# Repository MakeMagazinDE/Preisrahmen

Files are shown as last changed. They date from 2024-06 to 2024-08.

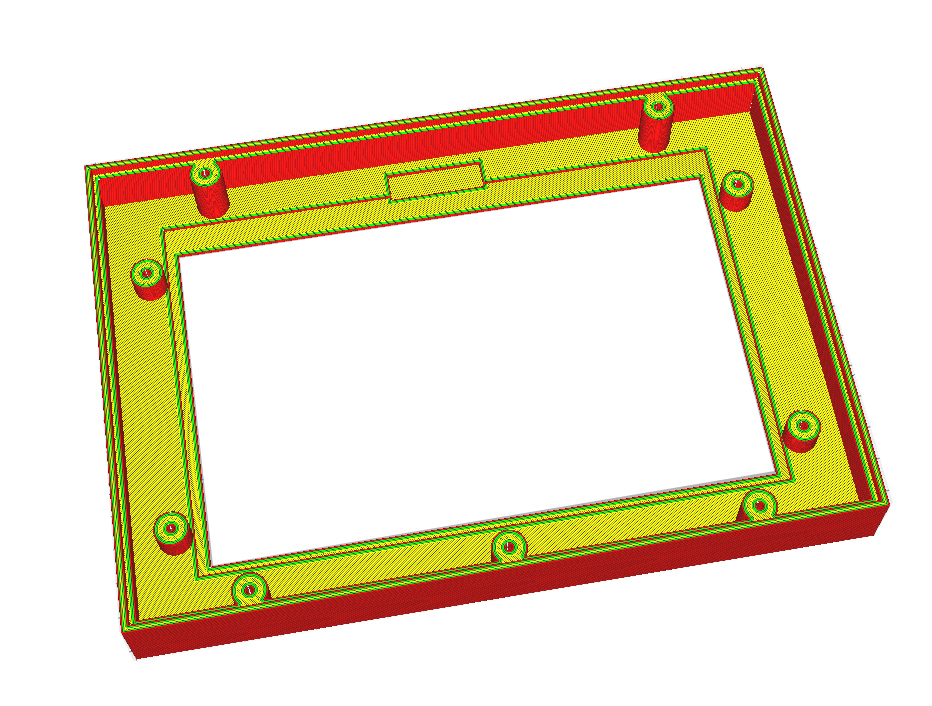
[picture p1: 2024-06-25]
3D-Druckdateien/3d-Rahmen.jpg

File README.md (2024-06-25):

GitHub Logo

Maker Media GmbH

***

# Preisrahmen

**Wer einen dynamischen Strompreisvertrag wählt, bekommt vom Energielieferanten keine festen kWh-Preise mehr, sondern stündlich wechselnde Tarife. Um die günstigsten Stunden optimal zu nutzen, haben wir unseren Preisrahmen entwickelt. Täglich ruft er die für den nächsten Tag festgelegten Preise ab und zeigt sie auf seinem ePaper-Display an.**

Preisrahmen

Der vollständige Artikel zum Projekt erscheint in der Make 4/24.

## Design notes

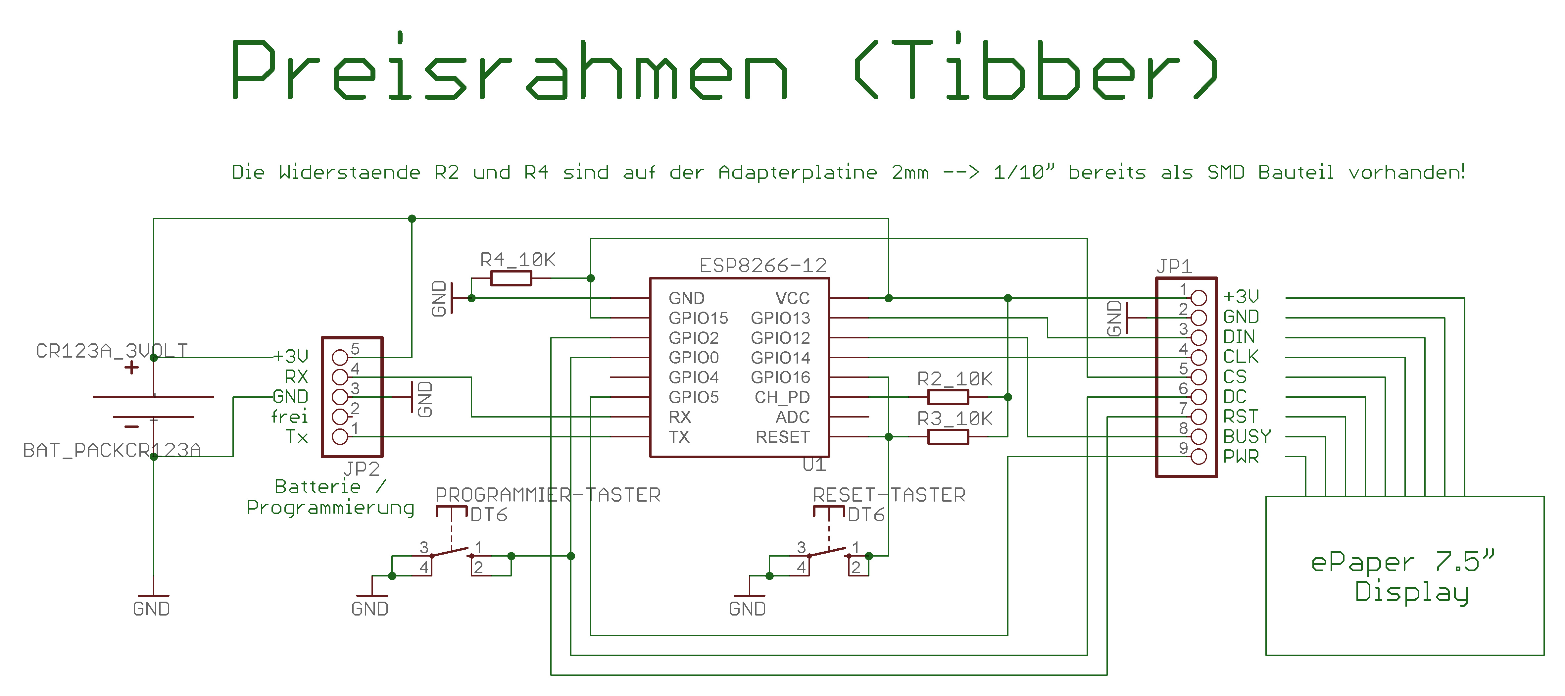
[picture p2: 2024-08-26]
Schaltplan_preisrahmen_26_08_2024.jpg

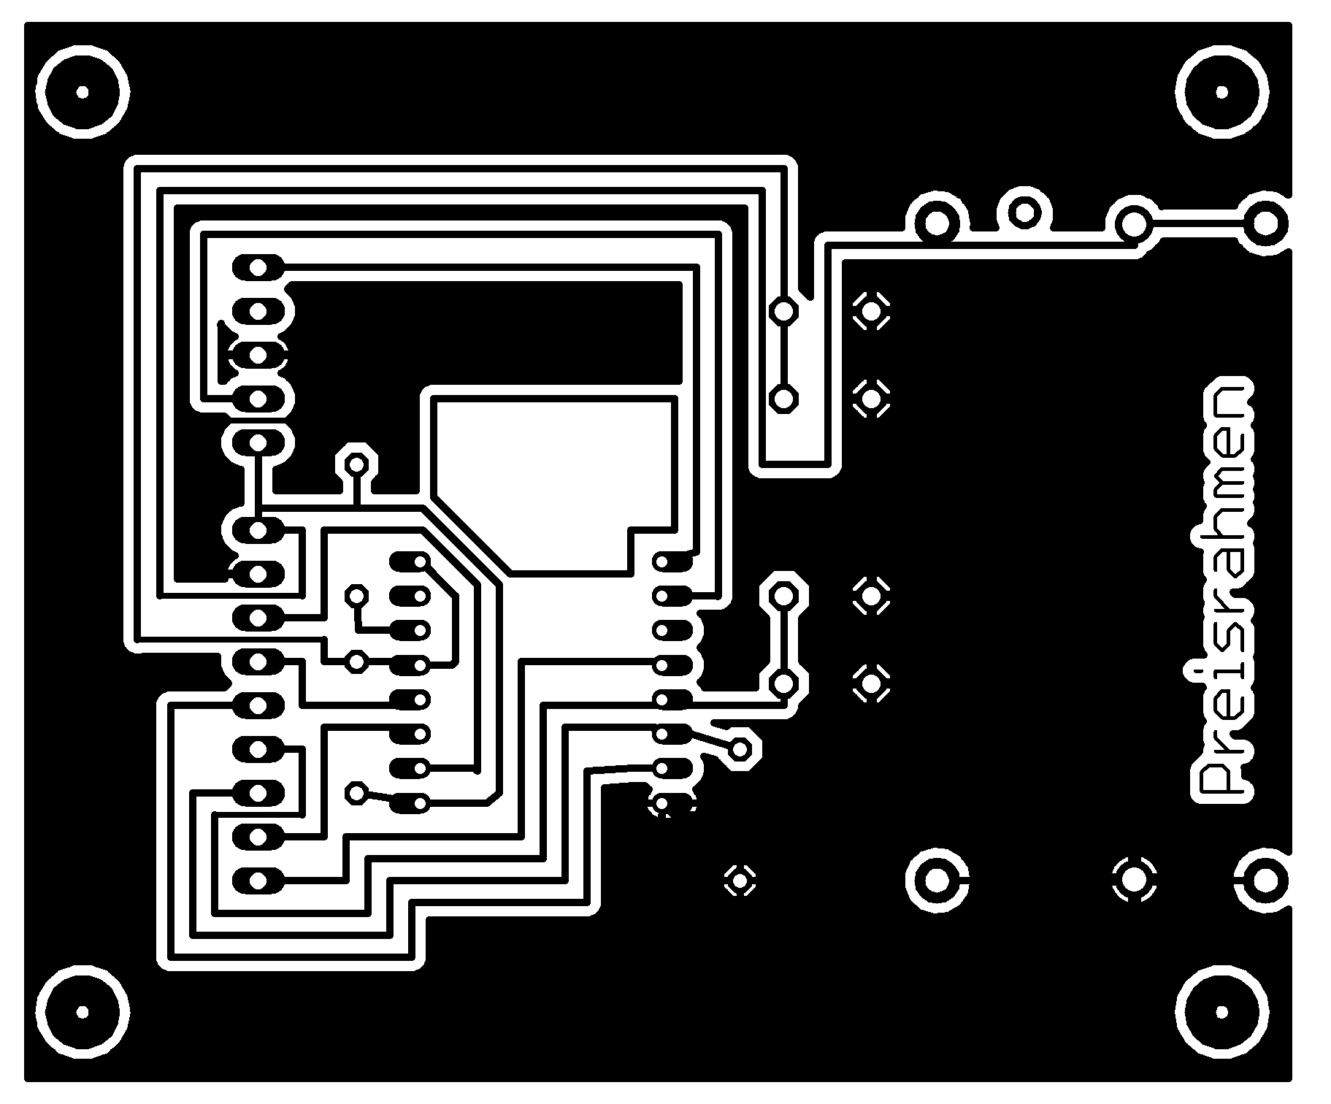
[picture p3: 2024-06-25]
Platine/Film.jpg

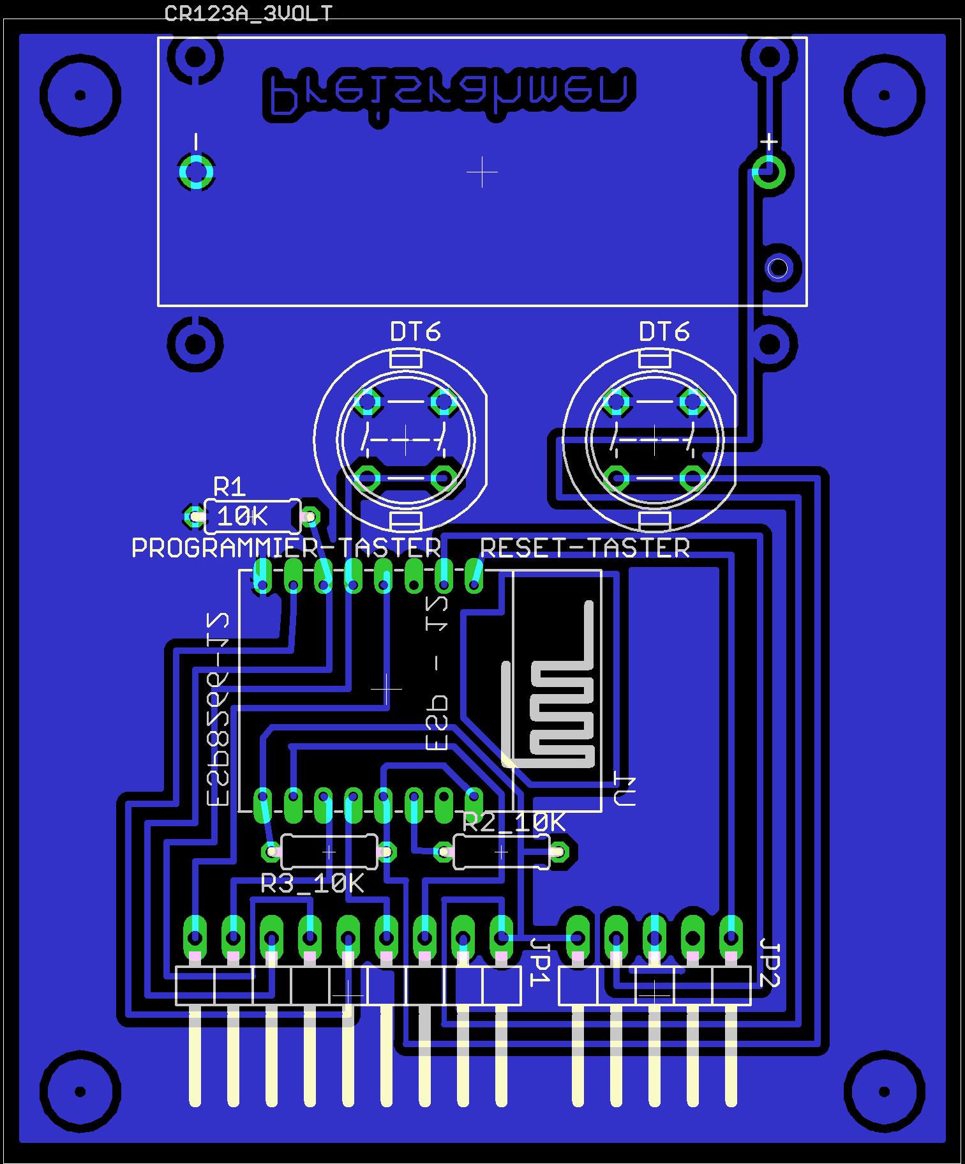
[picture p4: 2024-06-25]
Platine/Bestückungsplan.jpg

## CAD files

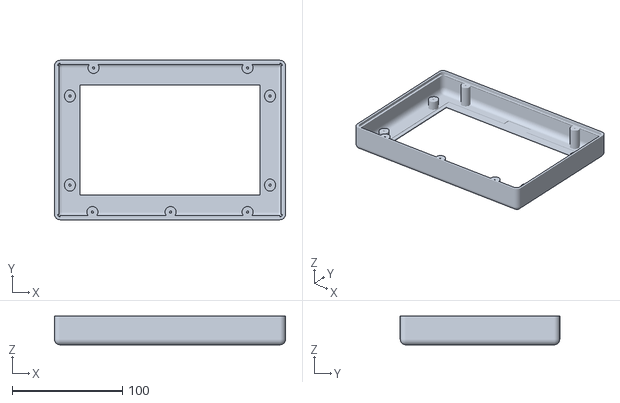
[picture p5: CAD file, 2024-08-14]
3D-Druckdateien/epaper7.5_mit_kofferecken (3).stl
210.0 x 145.0 x 26.0

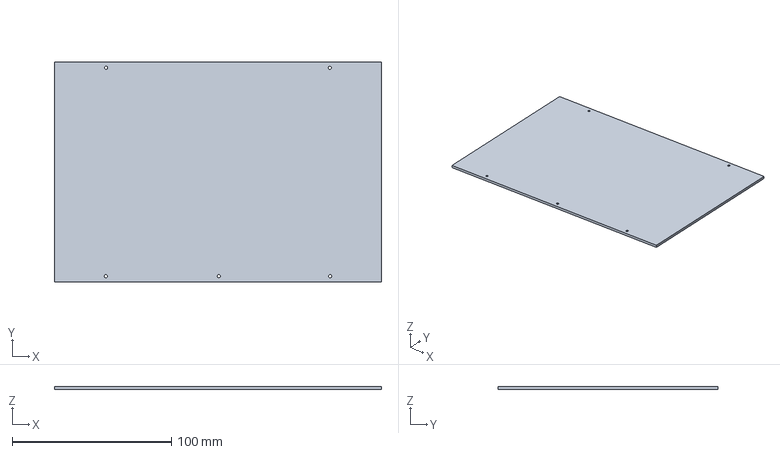
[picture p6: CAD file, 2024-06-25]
3D-Druckdateien/Cura_Rueckwand-ePaper7.5-1 (4).3mf
205.5 x 138.5 x 2.00 mm

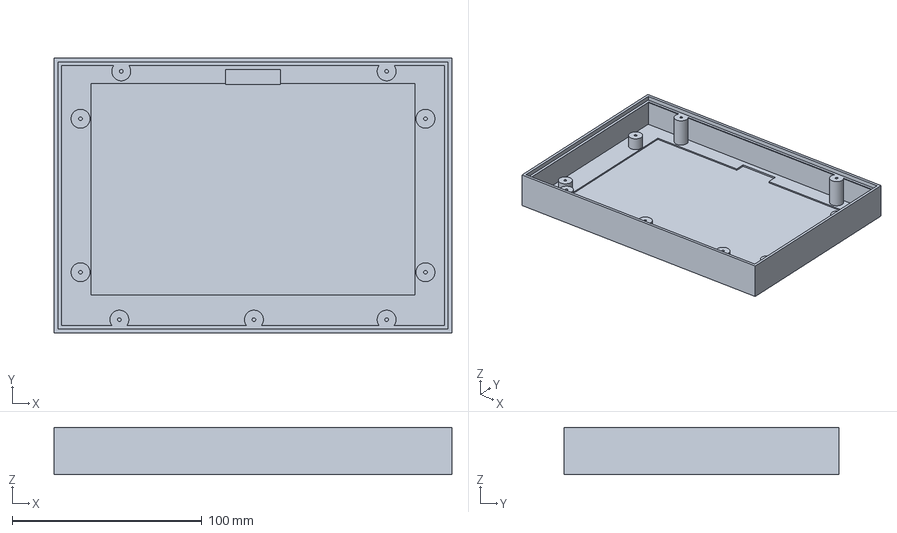
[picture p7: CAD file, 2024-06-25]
3D-Druckdateien/Cura_Rahmen-ePaper7.5-1 (1).3mf
210.0 x 145.0 x 25.0 mm

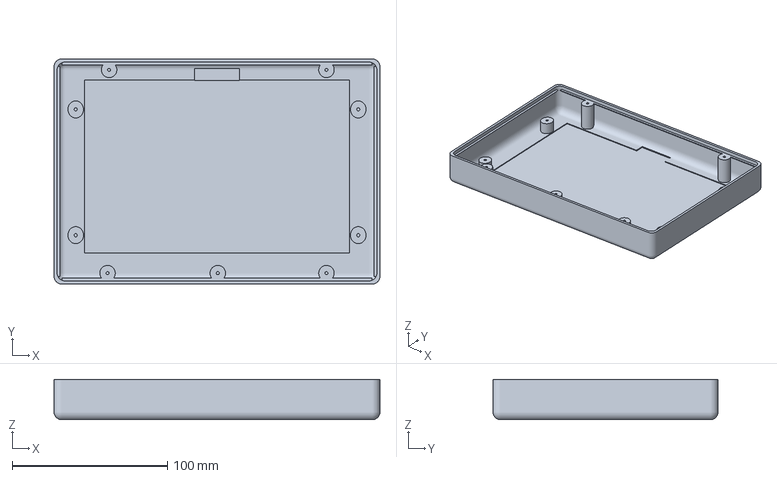
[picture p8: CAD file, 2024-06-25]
3D-Druckdateien/Rueckseite_epaper7.5kofferecken.3mf
210.0 x 145.0 x 26.0 mm

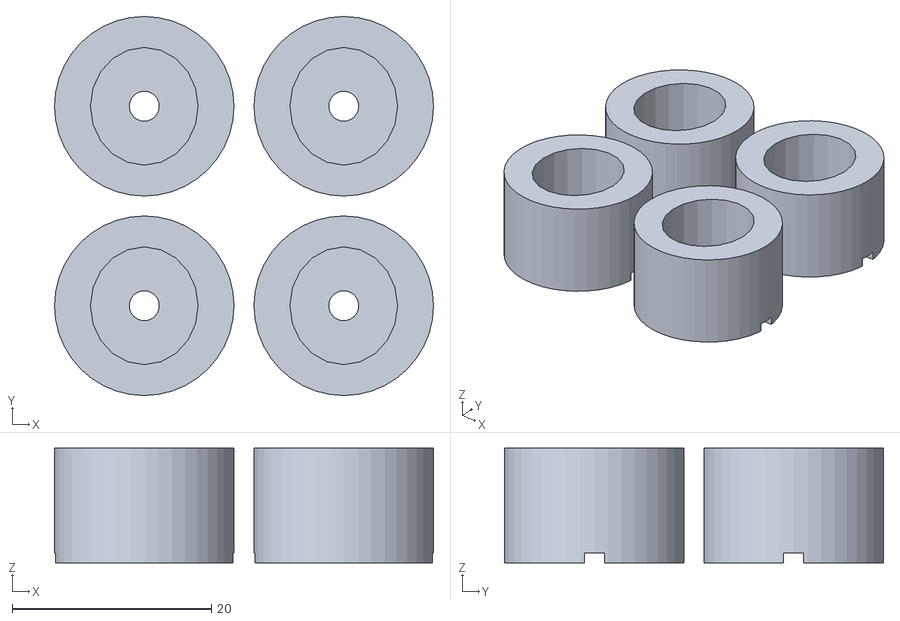
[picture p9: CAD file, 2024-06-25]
3D-Druckdateien/4xHalter_epaper7.5.stl
38.0 x 38.0 x 11.5

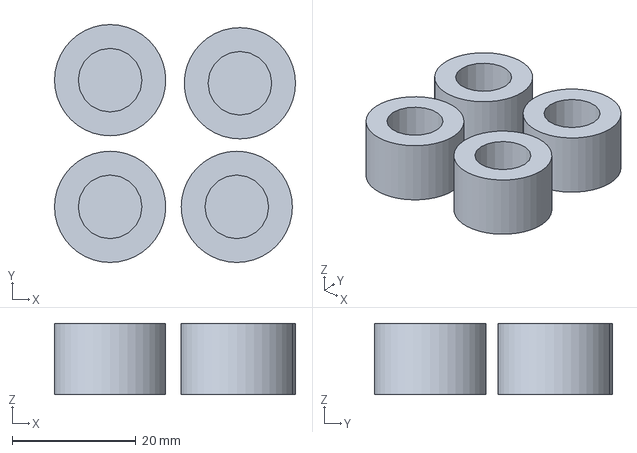
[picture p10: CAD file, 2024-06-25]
3D-Druckdateien/Befestigung_Rahmen-ePaper7.5-1 (3).3mf
39.0 x 38.5 x 11.5 mm

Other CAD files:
3D-Druckdateien/Rueckseite_epaper7.5kofferecken.stl

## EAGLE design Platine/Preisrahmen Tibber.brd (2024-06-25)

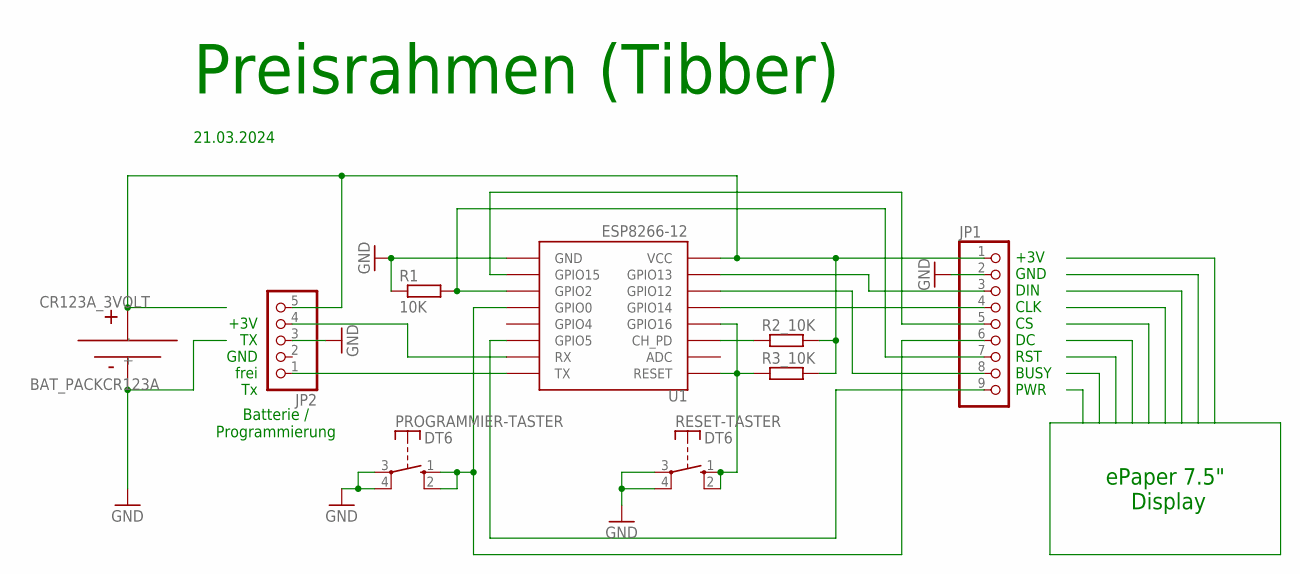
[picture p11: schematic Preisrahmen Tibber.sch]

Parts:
CR123A_3VOLT: BAT_PACKCR123A; BH123A
JP1: PINHD-1X9/90; 1X09/90
JP2: PINHD-1X5/90; 1X05/90
PROGRAMMIER-TASTER: DT6
R1: 10K; 0207/7
R2_10K, R3_10K: R-EU_0207/7; 0207/7
RESET-TASTER: DT6
U1: ESP8266-12; ESP12

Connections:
GND: CR123A_3VOLT.-, JP1.2, JP2.3, PROGRAMMIER-TASTER.3, PROGRAMMIER-TASTER.4, R1.1, RESET-TASTER.3, RESET-TASTER.4, U1.GND
unnamed: R2_10K.1, U1.CH_PD
unnamed: R3_10K.1, RESET-TASTER.1 (S), RESET-TASTER.2 (S), U1.GPIO16, U1.RESET
unnamed: JP1.7, R1.2, U1.GPIO2
unnamed: JP1.6, PROGRAMMIER-TASTER.1 (S), PROGRAMMIER-TASTER.2 (S), U1.GPIO0
unnamed: JP2.1, U1.TX
unnamed: JP2.4, U1.RX
unnamed: JP1.9, U1.GPIO5
unnamed: JP1.3, U1.GPIO13
unnamed: JP1.4, U1.GPIO14
unnamed: JP1.5, U1.GPIO15
unnamed: CR123A_3VOLT.+, JP1.1, JP2.5, R2_10K.2, R3_10K.2, U1.VCC
unnamed: JP1.8, U1.GPIO12

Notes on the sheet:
Preisrahmen (Tibber)
21.03.2024
+3V TX GND frei Tx
+3V GND DIN CLK CS DC RST BUSY PWR
ePaper 7.5" Display
Batterie / Programmierung

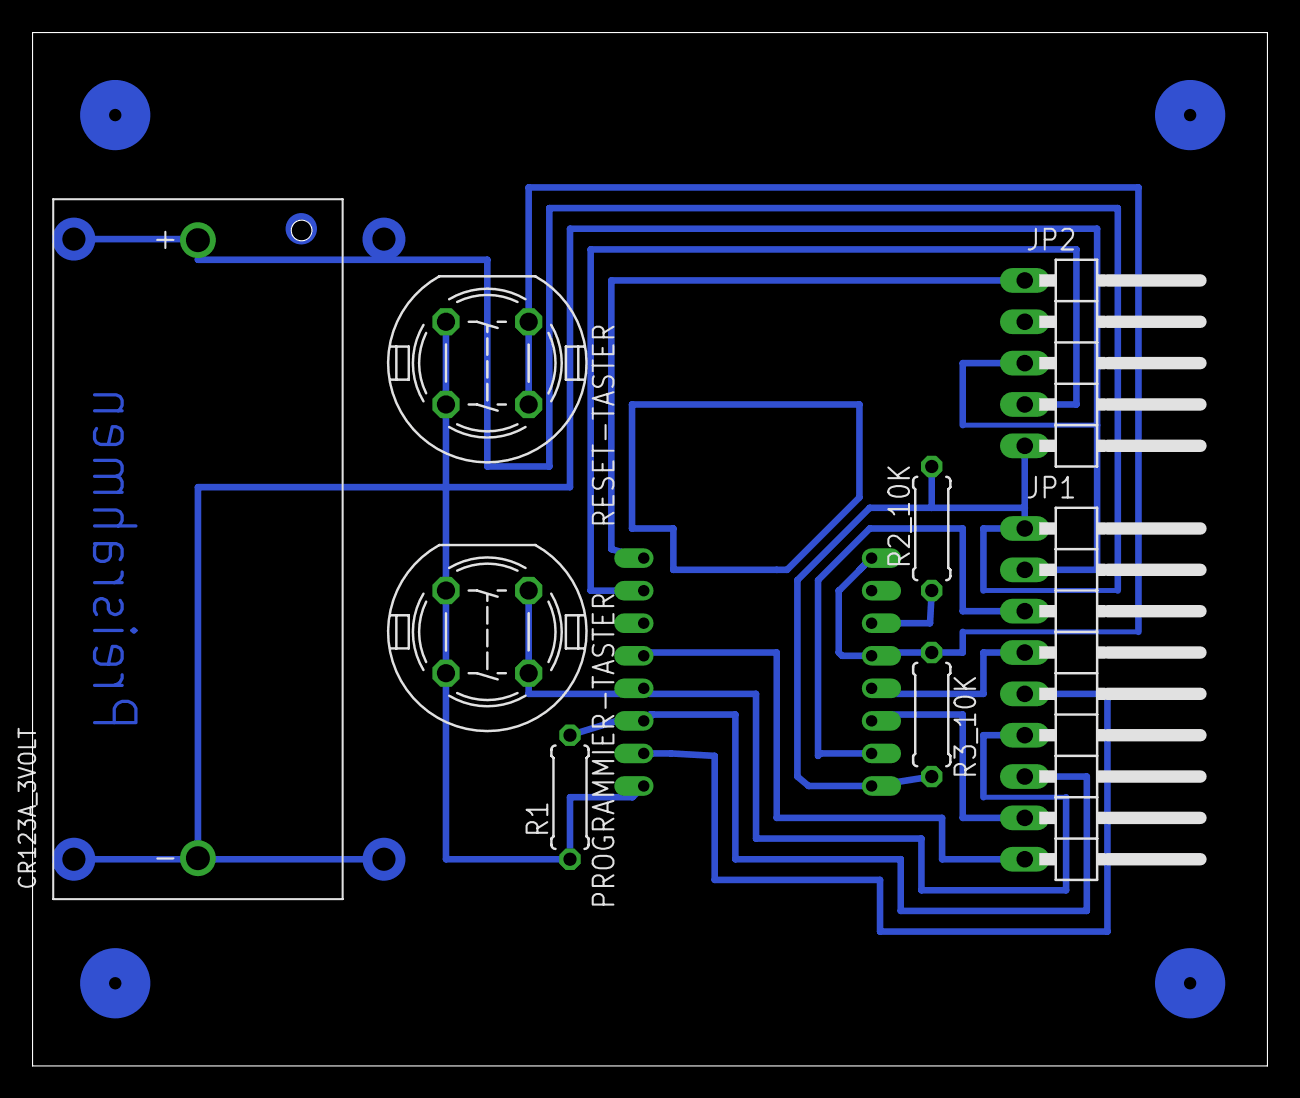
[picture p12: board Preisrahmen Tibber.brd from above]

Board: 2 copper layers, 75.9 x 63.5 mm, 9 parts (1 on the bottom side), 13 nets.

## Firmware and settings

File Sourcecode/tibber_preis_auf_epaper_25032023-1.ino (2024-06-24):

#include <dummy.h>

#define vers "Version: 11.05.2024 tibber MAKE "
const char *ssid = "Heise-Gaeste"; 
const char *password = "NurFuerHeiseGaeste!";  
const char *token = "5K4MVS-OjfWhK_4yrjOlFe1F6kJXPVf7eQYggo8ebAE"; // Demo Token durch eigenen Token ersetzen!!!
const char *tibberApi = "https://api.tibber.com/v1-beta/gql";
//############### ePaper "Gedoens" ###########################################################
#define EPD_CS SS
#define MAX_DISPLAY_BUFFER_SIZE (81920ul-34000ul-5000ul) // ~34000 base use, change 5000 to your application use
#define GxEPD2_DISPLAY_CLASS GxEPD2_BW
#define GxEPD2_DRIVER_CLASS GxEPD2_750_T7  // GDEW075T7   800x480, EK79655 (GD7965), (WFT0583CZ61)
#define MAX_HEIGHT(EPD) (EPD::HEIGHT <= (MAX_DISPLAY_BUFFER_SIZE) / (EPD::WIDTH / 2) ? EPD::HEIGHT : (MAX_DISPLAY_BUFFER_SIZE) / (EPD::WIDTH / 2))
//#if defined uwe #else #endif
#define ENABLE_GxEPD2_GFX 0  //wenn ohne Grauwerte
#include <GxEPD2_BW.h> 
#define GxEPD_LIGHTGREY GxEPD_BLACK
//Pins ePapaer an ESP8266: VCC=gr=3,3V, GND=br=GND, DIN=bl=Gpio13=D7=MOSI, CLK=ge=D5=Gpio14=SCLK, CS=or=D8=Gpio15=CS, DC=gn=D3=Gpio0, RST=ws=D4=Gpio2, BUSY=vi=D6=Gpio12=MISO, PWR=rt=3,3V
GxEPD2_DISPLAY_CLASS<GxEPD2_DRIVER_CLASS, MAX_HEIGHT(GxEPD2_DRIVER_CLASS)> display(GxEPD2_DRIVER_CLASS(/*CS=D8*/ EPD_CS, /*DC=D3*/ 0, /*RST=D4*/ 2, /*BUSY=D2*/ 4));
#include <Fonts/FreeMonoBold9pt7b.h>
//############### ePaper "Gedoens" Ende ######################################################
#include <ESP8266WiFi.h> 
#include <ESP8266HTTPClient.h> 
#include <WiFiClientSecureBearSSL.h> 
#include <ArduinoJson.h>  
#include <time.h>
#include "ota.h" 
#include "Internetzeit.h"
#define ePaper_on 5 //D1 = GPIo5
#define LED 2 //D4
#define AN LOW
#define AUS HIGH
#define RTCMEMORYSTART 65 //1.freier Speicherplatz im RTC
ADC_MODE(ADC_VCC);
char buf[200]; // Buffer für sprintf
int preis[2][24] ; //24h = 24 Preise, jeweils für den aktuellen und den folgenden Tag
int min1[2]={0,0}, max1[2]={0,0}; //jeweils für den aktuellen und den folgenden Tag
long preismittel[2]={0, 0}; //Mittelwert, jeweils für den aktuellen und den folgenden Tag
long mittelwert[2]={0,0};   //hier jetzt der Mittelwert von 13-24 Uhr des aktuellen Tages und 0-23 Uhr des folgenden Tages fuer epaper-Darstellung
int mini=30000, maxi=0, min_abgerundet, max_aufgerundet, spreizung; //fuer ePaper Darstellung
WiFiClientSecure client;  
boolean wlan_ok=false;
uint32_t bootcount, deepsleeptime; //deepsleeptime knapp unter 2hoch32, daher 22 x booten, Bootcount wird in der rtc des ESP gespeichert
unsigned long zeit_bis13; //hier wird die Zahl der Sekunden bis zum naechsten 13 Uhr gespeichert
StaticJsonDocument<1501> doc; //Speicher für die json-Daten vor dem Deserialisieren
//************************************************************
void setup() {
  unsigned long t=micros();
  Serial.begin(115200);
  Serial.print(vers);Serial.print("\nWaking up..., ESP.getResetReason: "); Serial.println(ESP.getResetReason().c_str());
  // die deepsleep Zeit wir in Mikrosekunden angegeben und beträgt maximal 2hoch32, also etwas mehr als 4 Milliarden, was ca. 70 Minuten entspricht
  // Der ESP soll aber 24h schlafen, also sorgt der nachfolgende Algorythmus dafür das der ESP nach knapp 70 Minuten kurz aufwacht 
  // (dauert ca 1,5 millisek.), den bootcounter erhöht und im nichtfluechtigem rtc Speicher ablegt und wieder schlafen geht. 
  // Ob das System aus dem deepsleep kommt oderneu eingeschaltet wurde, wird über ESP.getReason ermittelt.
  strcpy(buf,ESP.getResetReason().c_str());
  if(buf[0]=='D') { //D steht für DeepSleeep, weitere Faelle waeren z.B. 'P'ower on oder 'S'oftware watchdog . . . 
    ESP.rtcUserMemoryRead(RTCMEMORYSTART, &bootcount, sizeof(bootcount)); //Counter aus dem ESP RTC (RealTimeClock) lesen
    if(bootcount<21) {
      bootcount++;
      ESP.rtcUserMemoryWrite(RTCMEMORYSTART, &bootcount, sizeof(bootcount)); //Serial.print("bootcount = "); Serial.println(bootcount); 
      ESP.rtcUserMemoryRead(RTCMEMORYSTART+1, &deepsleeptime, sizeof(deepsleeptime));
      Serial.print(bootcount); Serial.print(" =bootcount, deepsleeptime= ");Serial.println(deepsleeptime);
      if(bootcount==21) {
        ESP.deepSleep(deepsleeptime, WAKE_RFCAL); delay(100); // nach dem Aufwachen WLAN ein
      }
      ESP.deepSleep(deepsleeptime, WAKE_RF_DISABLED); delay(100); //nach dem Aufwachen WLAN aus
    }
  }
  bootcount=0; //kein Deep Sleep, sondern echter Neustart oder es ist kurz nach 13:oo:oo Uhr
  ESP.rtcUserMemoryWrite(RTCMEMORYSTART, &bootcount, sizeof(bootcount));
  pinMode(ePaper_on, OUTPUT);
  digitalWrite(ePaper_on, HIGH); 
  WiFi.begin(ssid, password);
  Serial.println("Connecting to WiFi...");  // Wait for WiFi connection
  for(int timeout=20; timeout >=0; timeout--) { //max 10 Sekunden auf WLAN Verbindung warten
    if (WiFi.status() == WL_CONNECTED) {
      wlan_ok=true;
      break;
    }
    delay(500);
    Serial.print(".");
  }  
  sprintf(buf,"\nconnected, address=%s; Hostname=%s, Version= %s\r\n",WiFi.localIP().toString().c_str(),WiFi.hostname().c_str(),vers);  Serial.print(buf);
  //############### Berechne deep sleep time ######################
  if(wlan_ok==true) {
    showTime(); showTime(); // Internetzeit holen, beim 1. Aufruf sind die Sekunden falsch, daher 2x
    if(tm.tm_hour>=13) zeit_bis13=(12+24-tm.tm_hour)*3600; // der Rest bis zur 13. Stunde wird mit Minuten und Sekunden aufgefüllt
    else              zeit_bis13=(12   -tm.tm_hour)*3600;
    zeit_bis13=zeit_bis13+(59-tm.tm_min)*60;
    zeit_bis13=zeit_bis13+(59-tm.tm_sec)+30*60;  //30*60 = 30 Minuten zusätzlich wegen ggf. Ungenauigkeit um sicher nach 13.oo Uhr zu "landen"
    zeit_bis13=(zeit_bis13*10000+21)/22; //1. Aufrunden und 2. durch 22 Zyklen teilen damit das spätere Ergebnis sicher in 32 Bit passt
    deepsleeptime = zeit_bis13*100; // deepsleep Zeit in Mikrosekunden
    //############### Berechne deep sleep time ENDE #################
    sprintf(buf,"Zeit: %s, %02d.%02d.%04d %02d:%02d:%02d, bootcount: %d deepsleeptime: ",wochentag[tm.tm_wday],tm.tm_mday,tm.tm_mon,tm.tm_year,tm.tm_hour,tm.tm_min,tm.tm_sec, bootcount);
    Serial.print(buf);Serial.println(deepsleeptime); //sprintf kann keine unsigned long ausgeben, daher Serial.print
    ESP.rtcUserMemoryWrite(RTCMEMORYSTART+1, &deepsleeptime, sizeof(deepsleeptime));
    // jetzt das eigentliche Programm
    hole_tibber_preise();
    WiFi.mode(WIFI_OFF); //WLAN aus um Strom zu sparen
    epaper_ermittele_minmax(); //fuer den ersten Tag erst ab 13.oo Uhr
  }
  else deepsleeptime=(3600*1000/22)*1000*10; //1h = 3600 Sek.*10 =10h in mikrosekunden neu versuchen;
  display.init(115200, true, 2, false); // USE THIS for epaper Waveshare boards with "clever" reset circuit, 2ms reset pulse
  sprintf(buf,"\nePaper Display mit WIDTH: %d, Hoehe: %d\n", display.epd2.WIDTH, display.epd2.HEIGHT); Serial.print(buf);
  epaper_ausgabe();
  for(int cnt=0;cnt<6;cnt++) {delay(1000); Serial.print(".");}
  //delay(20000);
  Serial.println(" gehe in deep Sleep");
  ESP.deepSleep(deepsleeptime, WAKE_RF_DISABLED); delay(100);
}   
//************************************************************
void loop() {}
//************************************************************
void epaper_ermittele_minmax() {
  for(int h=13;h<24;h++) { //min, max, mittelw Werte für den ersten Tag ermitteln, 13-23 Uhr
    if(preis[0][h]<mini) mini=preis[0][h];
    if(preis[0][h]>maxi) maxi=preis[0][h];
    mittelwert[0] = mittelwert[0] + preis[0][h]; 
  }
  for(int h=0;h<24;h++) { //min, max, mittelw Werte für den zweiten Tag ermitteln, 0-23 Uhr
    if(preis[1][h]<mini) mini=preis[1][h];
    if(preis[1][h]>maxi) maxi=preis[1][h];
    mittelwert[1] = mittelwert[1] + preis[1][h]; 
  }
  mittelwert[0]=mittelwert[0]/11; // Tag1 von 13-23 Uhr
  mittelwert[1]=mittelwert[1]/24; // Tag2 von 0-23 Uhr
  min_abgerundet =(mini/100-2)*100; //auf voll 100  abgerundet -200
  max_aufgerundet=(maxi/100+1)*100; //auf voll 100 aufgerundet +100
  spreizung=max_aufgerundet - min_abgerundet; // Schwankungsbreite
  sprintf(buf,"Mittelwert0: %4d, Mittelwert1: %4d, Minimum: %4d, Maximum: %4d, min_abgerundet: %4d, max_aufgerundet: %4d, spreizung: %4d\n", 
               mittelwert[0], mittelwert[1], mini, maxi, min_abgerundet, max_aufgerundet, spreizung); Serial.print(buf);
}
//*****************************************************************************
void epaper_ausgabe() {
  display.setRotation(2);
  display.setFont(&FreeMonoBold9pt7b); //alternativ: display.setFont(0);
  display.fillScreen(GxEPD_WHITE); 
  display.setTextColor(GxEPD_BLACK);
  display.setFullWindow();
  display.firstPage();
  do {
    display.fillScreen(GxEPD_WHITE);
//####### Balken zeichnen ############################################
    int d=0, p=0;
    for(int h=13;h<48;h++) { 
      if( h>23 && d==0) {
        d=1; 
        p=24;
      }
      int balkenhoehe= long (-380* ( (preis[d][h-p] - min_abgerundet)*100 / spreizung)/100) ; //max. 380 Pixel hoch
      int hh=(h-13)*20;
      display.fillRect(/*x0*/90+hh, /*y=*/display.height() - 50, 8, balkenhoehe, GxEPD_LIGHTGREY);
      //sprintf(buf,"h: %d, d: %d, p: %d, preis[d][h-p]: %d, Balkenhoehe in Pixel: %d, Balkenhoehe_Proz.: %d\n", h, d, p, preis[d][h-p], balkenhoehe, ((preis[d][h-p] - min_abgerundet)*100) / spreizung ); Serial.print(buf);
    }
//####### Balken zeichnen Ende #######################################
//####### Y-Achse schreiben  #########################################
    int unterteilung=6;
    int delta_spreizung=spreizung/(unterteilung)/100; // auf ganze Cent abgerundet 
    int y_achse=0;
    while(true) {
      int y_abstand = display.height() - (50+ (y_achse* 380 * delta_spreizung /(spreizung/100)));
      //int y_abstand = display.height() - 1*(50+ y_achse* 380/(unterteilung));
      display.drawLine(/*x=*/80, y_abstand,display.width()-20 , y_abstand,GxEPD_BLACK);
      display.setCursor(15 , y_abstand); 
      display.print(delta_spreizung * y_achse + min_abgerundet/100) ;
      //sprintf(buf, "delta_spreizung: %d, y_achse: %d, y_abstand absolut in Pixel: %d\n", delta_spreizung, y_achse, y_abstand); Serial.print(buf);
      if( y_abstand < (display.height()-(380+0)) ) break;
      y_achse++;
      if(y_achse >10) break; //Notbremse
    }
    display.setCursor(13 , display.height() -465); //Y-Achse beschriften  
    display.print("Cent"); 
    display.setCursor(13 , display.height() -451); //Y-Achse beschriften  
    display.print("/kWh"); 
//####### Y-Achse schreiben Ende######################################
//####### Version, Spannung, Feldstärke, letzte Aktualisierung #######
    display.setFont(0);
    display.setCursor(15,473);
    sprintf(buf,"%s, RSSI: %d, Spannung [mV]: %d, letzte Aktualisierung: %s, %02d.%02d.%04d %02d:%02d:%02d",
              vers, wifi_station_get_rssi(),ESP.getVcc(),wochentag[tm.tm_wday],tm.tm_mday,tm.tm_mon,tm.tm_year,tm.tm_hour,tm.tm_min,tm.tm_sec);
    display.print(buf);
    display.setFont(&FreeMonoBold9pt7b);
//####### Version, Spannung, Feldstärke, letzte Aktualisierung Ende ##
//####### X-Achse schreiben ##########################################
    int yyy=display.height() -35;
    for(int yt=0;yt<18;yt++) {  //X-Achse beschriften  
      int ytt=yt*40;
      int h=13+2*yt;
      if(h>23) h=h-24;
      int sp=0; if(h<10) sp=6;
      display.setCursor(82 + ytt+sp, yyy);
      display.print(h); 
    }
    sprintf(buf,"%s,%2d.%02d.%04d          Stunde          ",wochentag[tm.tm_wday],tm.tm_mday,tm.tm_mon,tm.tm_year);
    now = (now + 86400);localtime_r(&now, &tm);  tm.tm_year += 1900; tm.tm_mon += 1; //einen Tag (86400 Sekunden) vor für den naechsten Tag, wird mit Aufruf von showtime() in loop wieder richtig gesetzt
    sprintf(buf+strlen(buf),"%s,%2d.%02d.%04d",wochentag[tm.tm_wday],tm.tm_mday,tm.tm_mon,tm.tm_year);
    display.setCursor(135, display.height() -16);
    display.print(buf);
    display.setCursor(260, 20); //display.setCursor(300, 20);
    display.setTextSize(2);
    display.print("Preisrahmen");
    display.setTextSize(1);
    display.setCursor(520, 18);
    display.print("(Tibber)");
//####### X-Achse schreiben Ende #####################################
//####### Mittelwert Linien ##########################################
    //int mw0 = display.height() - 50 - (380 * (mittelwert[0] - min_abgerundet)) / spreizung ; //Mittelwert von 13-23Uhr
    int mw0 = display.height() - 50 - (380 * (preismittel[0] - min_abgerundet)) / spreizung ;  //Mittelwert von 0 - 23Uhr
    int mw1 = display.height() - 50 - (380 * (mittelwert[1] - min_abgerundet)) / spreizung ;
    for(p=0;p<11*20;p+=8) display.fillRect(/*x0*/80+p, /*y=*/mw0, /*Laenge*/2, /*Breite*/3, GxEPD_LIGHTGREY); //gestrichelte "dicke" Linie
    for(p=0;p<24*20;p+=8) display.fillRect(/*x0*/80+11*20+5+p, /*y=*/mw1, /*Laenge*/2, /*Breite*/3, GxEPD_LIGHTGREY);//gestrichelte "dicke" Linie
//####### Mittelwert Linien Ende #####################################
//####### Fehlerbehandlung ###########################################
    if(wlan_ok==false) {
      display.setCursor(260, 50); 
      display.setTextSize(2);
      display.print("K E I N   W L A N");
      display.setTextSize(1);
    }
    if(ESP.getVcc()<2700) {
      display.setCursor(260, 80); 
      display.print("Batterie unter 2,7 Volt, WECHSELN");
    }
//####### Fehlerbehandlung Ende ######################################
  }
  while (display.nextPage());
  Serial.println("ePaper schreiben Ende");
}
//*****************************************************************************************
void hole_tibber_preise() {
  WiFiClientSecure client; //HTTPS !!!
  client.setInsecure(); //the magic line, use with caution
  HTTPClient https;
  strcpy(buf, "Bearer ");
  strcat(buf, token);
  https.begin(client, tibberApi);
  https.addHeader("Content-Type", "application/json");  // add necessary headers
  https.addHeader("Authorization",  buf);           // add necessary headers
  String payload = "{\"query\": \"{viewer { homes { currentSubscription{ priceInfo{ today{ total  } tomorrow { total  }}}}}}\"} ";
  //char payload[100]; strcpy( payload, "{\"query\": \"{viewer { homes { currentSubscription{ priceInfo{ today{ total  } tomorrow { total  }}}}}}\"} " );
  Serial.print("STRING PAYLOAD: "); Serial.println(payload);
  int httpCode = https.POST(payload);
  if (httpCode == HTTP_CODE_OK) {
    String response = https.getString();
   // strcpy(response, https.getString() );
    Serial.println(response);
    DeserializationError error = deserializeJson(doc, response);
    if (error) Serial.println("\n\n################################# Error parsing JSON response ###########################\n");
    preise_aus_json();
  } else {
    Serial.println("something went wrong");
    Serial.println(httpCode);
  }
  https.end();
  client.stop();  // Disconnect from the server
}
//*****************************************************************************************
void preise_aus_json() { //Preise aus JSON STring extrahieren und in kompakter Tabelle ausgeben
  char buf[200]; 
  Serial.println("preise_aus_json    :");
  char tag[2][9]={"today", "tomorrow"};
  double preis_in_doublefloat;
  for(int to=0;to<2;to++) {
    for(int h=0;h<24;h++) {
      preis_in_doublefloat = doc["data"]["viewer"]["homes"][0]["currentSubscription"]["priceInfo"][tag[to]][h]["total"];
      preis[to][h] = int (10000*preis_in_doublefloat);
      sprintf(buf,"Tag= %9s, to=%2d, h=%2d, Preis= %4d\n", tag[to], to, h, preis[to][h]); Serial.print (buf);
      int h1; if(h==23) h1=0; else h1=h;
      if(h>0) {
        if(preis[to][ min1[to] ]>preis[to][h1])  min1[to]=h1;
        if(preis[to][ max1[to] ]<preis[to][h1])  max1[to]=h1;
      }
      preismittel[to] =preis[to][h] + preismittel[to]; //mittelwert berechnen Teil 1
    }
    preismittel[to] = preismittel[to] / 24;  //mittelwert berechnen Teil 2    
  }
  Serial.println("\n            Heute        ||||             Morgen"); // in kompakter Tabelle ausgeben
  for(int h1=0;h1<12;h1++) {
    sprintf(buf,"h=%2d: %4d || h=%2d: %4d |||| h=%2d: %4d || h=%2d: %4d ||\n", h1, preis[0][h1], h1+12, preis[0][h1+12], h1, preis[1][h1], h1+12, preis[1][h1+12]); Serial.print (buf);
  }
  sprintf(buf,            " Min h: %2d, %4d,        |||| Min h: %2d, %4d, \n", min1[0], preis[0][min1[0]],min1[1], preis[1][min1[1]]);
  sprintf(buf+strlen(buf)," Max h: %2d, %4d,        |||| Max h: %2d, %4d, \n",max1[0], preis[0][max1[0]],max1[1], preis[1][max1[1]]);
  sprintf(buf+strlen(buf),"Mittelwert: %4d         |||| Mittelwert: %4d\n\n",preismittel[0], preismittel[1]); Serial.print (buf);
  sprintf(buf,"   <h:%2d, >h:%2d, =:%4d  ||||   <h:%2d, >h:%2d, =:%4d \n", min1[0], max1[0], preismittel[0], min1[1], max1[1] ,preismittel[1]); Serial.print (buf);
}
//*****************************************************************************************
//                     0    1    2    3    4    5    6    7    8    9   10   11   12   13   14   15   16   17   18   19   20   21   22   23    Uhr
//int preis[2][24]={{2703,2685,2686,2674,2678,2687,2875,3020,2946,2774,2574,2508,2148,1939,2177,2368,2552,2745,2885,2840,2739,2661,2663,2601},//Preise zu Testzwecken vom 8.+9.3.2024
//                  {2562,2542,2528,2514,2467,2457,2489,2520,2520,2461,2281,1891,1875,1829,1888,2224,2515,2716,2817,2781,2689,2608,2609,2570}};//Preise zu Testzwecken vom 8.+9.3.2024
//   Min h: 13, 0.1939,          |||| Min h: 13, 0.1829,      
//   Max h:  7, 0.3020,          |||| Max h: 18, 0.2817,      
//  Mittelwert: 0.2630           |||| Mittelwert: 0.2431      
